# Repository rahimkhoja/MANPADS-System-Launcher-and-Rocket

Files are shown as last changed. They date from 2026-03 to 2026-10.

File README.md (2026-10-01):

# MANPADS Rocket & Launcher Prototype

> **Fork notice:** This is an enhanced fork of the original project. The simulation framework,
> firmware improvements, and documentation were developed with the assistance
> of [Cursor](https://cursor.com), an AI-powered code editor, running
> analysis on the Digital Research Alliance of Canada's Eureka HPC cluster.

---

## 30 Second Overview

30 Second Overview (https://www.youtube.com/shorts/zFn__6_LdTc)

## Full System Overview (5 Minutes)

Full System Overview (https://www.youtube.com/watch?v=DDO2EvXyncE&t=59s)

---

## Project Overview

A proof-of-concept prototype of a low-cost rocket launcher and guided rocket
system built using consumer electronics and 3D-printed components.

The rocket uses folding fins and canard stabilisation controlled by an onboard
ESP32 flight computer and MPU6050 IMU. The launcher integrates GPS, compass,
and barometric sensors to provide telemetry.

Total hardware cost: approximately **$96**.

---

## What's New in This Fork

### 6-DOF Flight Simulation
A complete rigid-body simulation modelling aerodynamic forces, motor thrust,
wind disturbance (Dryden turbulence), and quaternion-based attitude dynamics.
Used to optimise PID gains and validate flight reliability.

### PID Gain Optimisation
Differential evolution over roll PID (and optional **six-axis** roll+pitch
objective via `pid_optimizer.py --six-axis`). Expanded gain bounds (Kd up to 5).
Cluster: `run_pid_optimizer.sh` (roll-only default), `run_pid_sixaxis.sh` for
pitch-augmented tuning.

### Monte Carlo Reliability Analysis
Statistical assessment of flight performance under parameter uncertainty
(mass, thrust, wind, launch angle, sensor noise). Reports success rates
and confidence intervals.

### Extended Kalman Filter (V5 Firmware)
Drift-free attitude estimation fusing gyroscope and accelerometer data.
Automatic apogee detection. Backward-compatible with the V4 launcher.

### Aerodynamic Design Improvement
Barrowman method sweep of 38,880 configurations to find optimal fin, canard,
and nose cone geometry. Von Karman nose, larger folding fins, and boat tail
improved stability from -4.3 to +1.1 calibres and increased roll authority by
40x. Candidate STLs generated parametrically for CFD validation.

### OpenFOAM CFD Integration
Automated steady-state RANS (k-omega SST) pipeline with snappyHexMesh,
parametric Python driver, and SLURM job scripts. **`run_cfd.sh` uses
`--serial-mesh`** (serial snappyHexMesh, parallel `simpleFoam`) and sources
Lmod under bash for reliable OpenFOAM modules on Eureka.

### Rail Launcher Redesign
The improved rocket's canards exceed the original 95 mm tube bore. A parametric
rail launcher (two parallel 2020 aluminium extrusion rails + base plate) replaces
the tube design, with nylon rail buttons on the rocket body.

### Material Recommendations
See [MATERIALS.md](docs/MATERIALS.md) for recommended materials per component.

### HPC Integration
SLURM job scripts for the Eureka cluster with proper module loading,
parallel execution, and automated pipelines.

---

## Repository Structure

```
├── Firmware/
│   ├── Rocket/src/            # ESP32 flight computer (V4 + V5)
│   ├── Launcher/src/          # ESP32 ground station
│   └── dashboard.py           # Python GUI
├── Simulation/
│   ├── src/                   # 6-DOF sim, optimiser, Monte Carlo, Barrowman
│   ├── cfd/                   # OpenFOAM templates and CFD driver
│   ├── jobs/                  # SLURM job scripts
│   └── results/               # Output data and candidate STLs
├── cad/                       # STL exports (Unix-friendly names)
│   └── fusion360/             # Original Fusion 360 .f3z archives
├── Mechanical/                # Legacy CAD location
├── OpenRocket/                # Aerodynamic stability analysis
└── docs/
    ├── AERODYNAMICS.md        # Barrowman analysis, design sweep, CFD
    ├── WIRING.md              # Pin assignments (verified against firmware)
    ├── SIMULATION.md          # Simulation framework guide
    ├── FIRMWARE_IMPROVEMENTS.md  # V4 → V5 changelog
    ├── CLUSTER_GUIDE.md       # Eureka HPC usage guide
    └── CONTRIBUTING.md        # Fork details, credits, workflow
```

---

## Quick Start

### Run the Simulation Locally
```bash
cd Simulation
python3 -m venv .venv && source .venv/bin/activate
pip install numpy scipy trimesh matplotlib
python src/rocket_dynamics.py
```
Motor **total impulse is enforced at 10 N·s** (thrust curve is scaled); expect
lower apogee than an unscaled 15 N plateau used in older runs.

### Run on Eureka Cluster
```bash
cd Simulation/jobs
sbatch run_validation.sh       # Quick smoke test (< 2 min)
sbatch run_full_analysis.sh    # Full pipeline (optimise → Monte Carlo)
```

### Build the Firmware
```bash
cd Firmware/Rocket
pio run                        # Compile
pio run -t upload              # Flash to ESP32
```

---

## Documentation

| Document | Description |
|---|---|
| [AERODYNAMICS.md](docs/AERODYNAMICS.md) | Barrowman analysis, design sweep, CFD pipeline |
| [SIMULATION.md](docs/SIMULATION.md) | Simulation physics, running instructions, parameters |
| [FIRMWARE_IMPROVEMENTS.md](docs/FIRMWARE_IMPROVEMENTS.md) | V4 → V5 firmware changes |
| [CLUSTER_GUIDE.md](docs/CLUSTER_GUIDE.md) | Eureka SLURM cluster usage |
| [CONTRIBUTING.md](docs/CONTRIBUTING.md) | Fork details, credits, AI workflow |
| [MATERIALS.md](docs/MATERIALS.md) | Recommended materials per component |
| [WIRING.md](docs/WIRING.md) | Pin assignments and telemetry protocol |

---

## Full Development Media
https://drive.google.com/drive/folders/17zpks6_R59H0iXJaGkTrtp1SzIFFAQtY?usp=drive_link

---

## Credits

- **Original project:** [rahimkhoja/MANPADS-System-Launcher-and-Rocket](https://github.com/rahimkhoja/MANPADS-System-Launcher-and-Rocket)
- **Fork maintainer:** Rahim Khoja ([@rahimkhoja](https://github.com/rahimkhoja))
- **AI-assisted development:** [Cursor](https://cursor.com)
- **HPC resources:** Digital Research Alliance of Canada — Eureka cluster

*Last updated: March 2026*

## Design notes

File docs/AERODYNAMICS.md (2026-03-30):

# Aerodynamic Analysis and Design Improvement

## Overview

This document describes the aerodynamic analysis pipeline used to improve the
rocket's all-weather performance. Starting from the original CAD geometry
(measured from STL exports), we applied the Barrowman method to sweep 38,880
design configurations, identified optimal fin/canard/nose parameters, and
validated the improvement through 6-DOF simulation with Monte Carlo analysis.

## Problem Statement

The original rocket achieved only **10.4% Monte Carlo success rate** under
0–5 m/s wind conditions. Root cause analysis revealed inadequate roll control
authority: the canards barely protruded beyond the 75 mm body tube, producing
insufficient torque to counter crosswind disturbances during the 1.2 s motor
burn.

## Baseline Geometry (from CAD STL)

Dimensions extracted from `cad/rocket_assembly.stl` using trimesh:

| Parameter | Value |
|---|---|
| Total length | 587 mm |
| Body OD | 75 mm |
| Nose length | 38 mm (ogive) |
| Nose shape | Short ogive |
| Canard protrusion | ~2.6 mm beyond body |
| Fin protrusion | ~2.6 mm beyond body |
| Launcher type | Rail launcher (replaced 95 mm tube) |

**Barrowman analysis of baseline:**
- CN_alpha total: 2.05 /rad
- CP: 124 mm from nose
- Stability: **-4.33 calibres** (unstable without large fins deployed)
- Cd0: 0.70
- Roll authority: 0.000007 Nm/(rad·Pa)

## Analysis Methods

### Barrowman Method (`Simulation/src/barrowman.py`)

Implementation of the Barrowman (1966) subsonic aerodynamic prediction method:

- **Normal force slopes** for nose, fins, and canards using the corrected
  Barrowman equation:
  ```
  CNa = K_fb × 4N(s/d)² / (1 + sqrt(1 + (AR/(2·cos(Λ)))²))
  ```
  where K_fb is the fin-body interference factor, N is fin count, s is
  semi-span, d is body diameter, AR is aspect ratio, and Λ is sweep angle.

- **Center of pressure** via weighted average of component CPs.

- **Drag estimation** using turbulent flat-plate skin friction (Schlichting),
  base drag, nose pressure drag, and fin leading-edge bluntness drag.

- **Roll authority** computed as canard count × planform area × 3D lift slope
  × moment arm.

Supports conical, ogive, Von Karman, and parabolic nose cones; trapezoidal
fins and canards with arbitrary sweep.

### Parametric Geometry Generator (`Simulation/src/rocket_geometry.py`)

Generates watertight STL meshes from parametric inputs using trimesh:
- Nose cone (conical, ogive, Von Karman)
- Cylindrical body tube with optional boat tail
- Trapezoidal fin sets at arbitrary positions
- Flat-plate canard sets

### OpenFOAM CFD (`Simulation/cfd/`)

Steady-state RANS simulation using k-omega SST turbulence model:
- `snappyHexMesh` for mesh generation around STL geometry
- `simpleFoam` for incompressible steady-state solution
- Parametric Python driver (`run_case.py`) sets velocity, AoA, and STL
- Extracts Cd, Cl, Cm from converged force coefficients

## Design Sweep Results

The design sweep (`Simulation/src/design_sweep.py`) evaluated **38,880
configurations** varying:

| Parameter | Range |
|---|---|
| Nose shape | conical, ogive, Von Karman |
| Nose length | 60 – 120 mm |
| Canard span | 10 – 30 mm |
| Canard root chord | 25 – 45 mm |
| Canard position | 60 – 100 mm from nose |
| Fin span | 30 – 60 mm |
| Fin root chord | 50 – 90 mm |
| Fin sweep | 30° – 60° |
| Boat tail | yes / no |

### Scoring Criteria

1. **Must fit** within 240 mm deployed OD (rail launcher, no tube bore constraint)
2. **Stability** ≥ 1.0 calibres (CP aft of CG)
3. **Maximise** roll authority (canard torque per radian)
4. **Minimise** drag (Cd0)

### Winning Configuration

| Parameter | Baseline | Improved | Change |
|---|---|---|---|
| Nose shape | ogive (38mm) | Von Karman (120mm) | 3.2× longer |
| Fin span | 2.6 mm | 60 mm | 23× larger |
| Fin root chord | ~20 mm | 70 mm | 3.5× larger |
| Fin sweep | ~45° | 30° | Lower sweep |
| Canard span | 2.6 mm | 20 mm | 7.7× larger |
| Canard root chord | ~20 mm | 45 mm | 2.3× larger |
| Boat tail | No | Yes (30mm, 60mm end ∅) | Added |
| **Stability** | **-4.33 cal** | **1.06 cal** | **Stable** |
| **CNa** | **2.05** | **8.21 /rad** | **4.0×** |
| **Cd0** | **0.70** | **0.64** | **-9%** |
| **Roll authority** | **7e-6** | **3e-4** | **40.8×** |

## Key Design Insights

1. **The body dominates**: A 75 mm diameter, 587 mm long body creates
   substantial destabilising lift (CN_alpha = 2.0 from nose alone). Without
   proportionally large fins, the rocket is deeply unstable.

2. **Folding fins must be aggressive**: The original 2.6 mm fin protrusion
   contributes almost nothing. To overcome the body destabilisation, fins need
   60 mm semi-span (total deployed OD ~195 mm).

3. **Longer nose reduces drag**: Extending from 38 mm ogive to 120 mm Von
   Karman reduces nose pressure drag substantially while barely affecting CP.

4. **Canard sizing for roll authority**: The 40× improvement in roll authority
   comes primarily from the 7.7× increase in canard span (torque scales with
   span × chord × lift slope).

5. **Boat tail reduces base drag**: A 30 mm boat tail taper reduces the base
   drag coefficient by approximately 25%.

## Simulation Validation

The improved design parameters are integrated into `Simulation/src/rocket_dynamics.py`
as the default `RocketParameters`. PID gains were re-optimised using differential
evolution on the Eureka cluster, followed by a 2000-run Monte Carlo analysis.

See `Simulation/results/` for the latest optimisation and Monte Carlo output
files.

## Reproducing the Results

```bash
# Run the design sweep (or re-use JSON + export STLs only)
cd Simulation/src
python design_sweep.py --output ../results/sweep_results.json --generate-stl ../results/candidate_stls/ --top 5
python design_sweep.py --from-json ../results/sweep_results.json --generate-stl ../results/candidate_stls --top 5

# Run the Barrowman calculator standalone
python barrowman.py

# Generate a parametric rocket STL
python rocket_geometry.py --nose vonkarman --nose-length 0.120 --fin-span 0.060 --canard-span 0.020 --boat-tail --output improved_rocket.stl

# Run CFD (requires OpenFOAM; --serial-mesh recommended on clusters)
cd ../cfd
python run_case.py --stl ../../cad/rocket_assembly.stl --velocity 40 --aoa 0 \
  --output baseline_cfd --serial-mesh

# Submit cluster jobs
cd ../jobs
sbatch run_design_sweep.sh
sbatch run_pid_optimizer.sh
sbatch --dependency=afterok:<pid_job_id> run_monte_carlo.sh
sbatch run_cfd.sh ../../cad/rocket_assembly.stl
```

## CFD Validation Status

CFD validation using OpenFOAM is in progress. Previous runs failed due to patch
naming mismatches and oversized background meshes. These issues have been fixed
(see `Simulation/cfd/template/` changes) and new runs are being submitted. Once
complete, CFD-derived Cd/Cl/Cm will be compared to Barrowman predictions.

## References

- J.S. Barrowman, "The Theoretical Prediction of the Center of Pressure",
  SRAD, 1966.
- OpenFOAM v2412, k-omega SST turbulence model.
- Schlichting, H., "Boundary Layer Theory", 7th ed., for skin friction
  correlations.

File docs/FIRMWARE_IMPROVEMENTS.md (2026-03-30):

# Firmware Improvements: V4 → V5

This document describes the changes made to the rocket flight computer firmware.

---

## Summary of Changes

| Feature | V4 (Original) | V5 (Improved) |
|---|---|---|
| Attitude estimation | Raw gyro integration | Extended Kalman Filter (EKF) |
| Drift compensation | None | Online gyro bias estimation |
| Control axes | Roll only | Roll only (PID, same structure)  |
| D-term source | Gyro rate | Gyro rate (minus estimated bias) |
| Integral term | None | Optional Ki with anti-windup |
| Default gains | Kp=0.5, Kd=0.2 | Kp=4.51, Ki=0.32, Kd=3.67 |
| Flight phase detection | Manual state machine | Automatic apogee detection |
| Telemetry format | Fixed V4 format | V4 (default) or V5 extended |
| I2C clock | Default (100 kHz) | 400 kHz Fast Mode |

---

## Extended Kalman Filter

The EKF fuses gyroscope and accelerometer data to produce drift-free attitude
estimates. It runs at the full IMU rate (~200 Hz) and estimates:

- Roll, pitch, yaw angles (quaternion internally)
- Gyroscope bias on all three axes

### Why it matters
The MPU6050 gyroscope has a typical bias instability of ~0.01°/s. With raw
integration (V4), this produces ~0.6°/minute of drift. Over a 10-second flight
this is small, but the EKF also filters high-frequency noise and provides
pitch/yaw estimates needed for future 3-axis control.

### Implementation
The EKF is implemented in `Firmware/Rocket/src/attitude_ekf.h` as a single header
(included by `main_improved.cpp`). `getGyroBiasXRaw()` exposes the X gyro bias
in **rad/s** (native EKF units). The D-term computation subtracts this from the
raw gyro reading before converting to deg/s, ensuring correct units throughout.

---

## PID Control

V5 keeps the same roll-only control architecture as V4: all four canards
deflect by the same amount. The PID output is:

```
output = Kp × roll + Ki × ∫roll + Kd × roll_rate
```

The D-term uses the gyro rate directly (with bias removed by the EKF), not
`d(error)/dt`. This avoids amplifying sensor noise through numerical
differentiation — a deliberate design choice inherited from V4.

### Gain Derivation
Default gains (Kp=4.51, Ki=0.32, Kd=3.67) were found via differential evolution
on the Eureka HPC cluster. See `docs/SIMULATION.md` and
`Simulation/results/best_gains_roll.json` for the optimised values.

### Serial commands
- **`PID,Kp,Kd`** — V4-compatible (sets Ki=0).
- **`PID,Kp,Ki,Kd`** — full three-term set (V5).

### Battery telemetry (optional)
GPIO **36** (ADC1) with a 100k:100k divider can report bus voltage in extended
telemetry (`readBatteryVoltage()`). Define `BATTERY_ADC_PIN` to `-1` to disable.

---

## Apogee Detection

V5 adds automatic transition to RECOVERY state:

1. During FLIGHT, monitor axial accelerometer reading
2. If |accel_x| < 0.5g for 500 ms continuously → declare apogee
3. Set state to RECOVERY, centre all canards
4. Send `RECOVERY` message to launcher

This replaces the V4 behaviour where the rocket stays in FLIGHT until power-off.

---

## Telemetry

### V4 Compatible Mode (default)
```
DATA,ax,ay,az,roll,rate,offset,state,Kp,Kd,skew
```
This is identical to V4 and works with the existing launcher firmware and
dashboard without modification.

### V5 Extended Mode
```
DATA,roll,pitch,yaw,offset,state,Kp,Ki,Kd,biasX,Vbatt
```
(`Vbatt` in volts; 0 if ADC disabled.)
Activated by sending `TELEMETRY_V5` command. Returns to V4 format with
`TELEMETRY_V4`.

---

## Backward Compatibility

V5 is a drop-in replacement for V4:
- Same pin assignments
- Same serial protocol
- Same default telemetry format
- Same command set (ARM, IGNITE, CALIBRATE, PID with optional Ki)
- Added commands (DISARM, TELEMETRY_V5, TELEMETRY_V4) are additive

The launcher firmware does not need to be modified.

---

## Building

The firmware is a PlatformIO project:

```bash
cd Firmware/Rocket
pio run                    # Compile
pio run --target upload    # Flash to ESP32
pio device monitor         # Serial monitor
```

Requires: Arduino framework, Adafruit MPU6050, ESP32Servo libraries.

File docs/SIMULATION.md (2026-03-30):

# Simulation Framework

A 6-DOF (six degrees of freedom) simulation of the canard-stabilised rocket, used
to optimise PID gains and validate flight reliability under uncertainty.

---

## Architecture

```
Simulation/
├── src/
│   ├── rocket_dynamics.py   # 6-DOF physics engine
│   ├── pid_optimizer.py     # DE + grid (roll-only or --six-axis)
│   ├── monte_carlo.py       # Statistical flight analysis
│   ├── design_sweep.py      # Barrowman sweep + STL export
│   ├── barrowman.py         # Barrowman aerodynamics
│   ├── rocket_geometry.py   # Parametric STL (trimesh)
│   ├── kalman_filter.py     # EKF implementation + C++ header generator
│   └── rl_controller.py     # Reinforcement learning (PPO) controller
├── jobs/
│   ├── run_validation.sh    # Quick < 2 min smoke test
│   ├── run_pid_optimizer.sh # Gain optimisation job
│   ├── run_monte_carlo.sh   # Monte Carlo analysis job
│   ├── run_rl_training.sh   # RL training job (GPU)
│   └── run_full_analysis.sh # Full pipeline
├── results/                 # Output directory for all runs
└── requirements.txt         # Python dependencies
```

---

## Physics Model (`rocket_dynamics.py`)

### Coordinate System
NED (North-East-Down). The body x-axis points along the rocket's longitudinal axis
(out the nose). Altitude is `-position[2]`.

### Forces Modelled
| Force | Description |
|---|---|
| Thrust | Trapezoidal profile **scaled** so ∫F dt = 10 N·s (C-class) |
| Gravity | Transformed to body frame via rotation matrix |
| Aerodynamic drag | Axial, based on Cd0 + incremental canard drag |
| Normal force | CNa-based restoring force from body + fins |
| Canard lift | Per-canard flat-plate lift from deflection angle |

### Moments Modelled
| Moment | Description |
|---|---|
| Roll/pitch/yaw (canard) | Differential [L,R,U,D] deflections → moments via `mix_canards` |
| Roll damping | Clp × q̄Sd × (d/2V) × p |
| Pitch restoring | CNa × stability_margin × α × q̄SL |
| Pitch damping | Cmq × q̄SL × (d/2V) × q |
| Yaw restoring | CNa × stability_margin × β × q̄SL |
| Yaw damping | Cnr × q̄SL × (d/2V) × r |

### Wind Model
Dryden-style turbulence with a first-order filter (time constant τ = 0.5 s) applied
to white noise. No per-timestep RNG reseeding — the state is continuous.

### Integration
4th-order Runge-Kutta at 200 Hz (dt = 0.005 s). Quaternion-based attitude to avoid
gimbal lock.

---

## Controller

`CanardController` runs independent PIDs on roll, pitch, and yaw (set pitch/yaw
gains to zero for roll-only, matching V4/V5 firmware). D-term uses body angular
rate in deg/s (same convention as the rocket firmware). Outputs are mixed to four
surfaces:

`[L,R,U,D] = mix(roll_cmd, pitch_cmd, yaw_cmd)` with saturation on the 4-vector.

`pitch_rms_burn` in results is RMS deviation from **launch pitch** during burn.

---

## Running Locally

```bash
cd Simulation/src

# Single simulation
python rocket_dynamics.py

# Small grid search
python pid_optimizer.py --method grid --grid-points 5 --wind-speeds 0 3 --num-runs 1

# Small Monte Carlo
python monte_carlo.py --runs 100 --seed 42

# Six-axis PID tuning (roll + pitch in objective)
python pid_optimizer.py --method de --six-axis --workers 8

# Re-export top STLs from saved sweep (no full 38k re-sweep)
python design_sweep.py --from-json ../results/sweep_results.json \
  --generate-stl ../results/candidate_stls --top 5

# Generate Kalman filter C++ header
python kalman_filter.py
```

---

## Running on SLURM Cluster

```bash
cd Simulation/jobs

# Quick validation (< 2 minutes, 4 CPUs)
sbatch run_validation.sh

# PID optimisation (DE, ~1-2 hours, 16 CPUs)
sbatch run_pid_optimizer.sh

# Monte Carlo (2000 runs, ~1 hour, 16 CPUs)
sbatch run_monte_carlo.sh

# Optional: six-axis PID (overwrites best_gains.json — merge with roll-only if needed)
sbatch run_pid_sixaxis.sh

# CFD sweep (bash + Lmod + --serial-mesh inside driver)
sbatch run_cfd.sh ../../cad/rocket_assembly.stl

# Full pipeline (optimise → MC → report)
sbatch run_full_analysis.sh
```

Monitor with `squeue -u $USER` and check output in `Simulation/results/`.

---

## PID Optimisation

### Differential Evolution
- Population: 40, Generations: 60 (defaults; jobs may use 30×40)
- Wind speeds: 0, 2, 5 m/s crosswind
- Objective: minimise roll RMS during burn; with `--six-axis`, roll RMS + 0.25× pitch RMS (burn)
- Roll-only bounds: Kp_roll ∈ [0.05, 5.0], Ki_roll ∈ [0, 0.5], Kd_roll ∈ [0.05, 5.0]
- Six-axis adds Kp/Ki/Kd_pitch with yaw slaved to 0.2× pitch gains in the optimiser

### Grid Search
For verification. Tests a grid of Kp × Ki × Kd values.

Results are saved to mode-specific files to prevent overwrites:
- `results/best_gains_roll.json` — roll-only DE/grid results
- `results/best_gains_sixaxis.json` — six-axis DE results
- `results/best_gains.json` — copy of the latest run (either mode)

**Warning:** `best_gains.json` is always overwritten by the most recent
optimiser run. Use the mode-specific files for reproducibility.

---

## Monte Carlo Analysis

- Randomises: mass, CG, inertia, drag, thrust, wind speed/direction, launch angle
- Success criteria: altitude > 20 m, roll RMS during burn < 15°; if `Kp_pitch > 0.01`, also pitch RMS (burn) < 30°
- Default: 2000 runs with parallel execution
- Reports success rate, altitude distribution, roll statistics; **`elapsed_seconds`** is recorded correctly in the JSON summary

Results are saved to `results/monte_carlo_results.json`.

---

## Key Parameters (Improved Design)

| Parameter | Value | Source |
|---|---|---|
| Mass | 200 g | BOM estimate |
| Length | 669 mm | STL measurement (120mm nose + 549mm) |
| Diameter | 75 mm | STL measurement |
| Stability margin | 1.06 cal | Barrowman analysis |
| Motor impulse | 10 N·s | C-class solid |
| Peak thrust | 15 N | Motor data |
| Burn time | 1.2 s | Motor data |
| Canard area | 9.0 cm²  | Per canard (20×45 mm planform, improved) |
| Canard span | 20 mm | Semi-span beyond body |
| Fin span | 60 mm | Semi-span, folding |
| CNa | 8.2/rad  | Barrowman |
| Cd0 | 0.64 | Barrowman (Von Karman + boat tail) |

See [AERODYNAMICS.md](AERODYNAMICS.md) for the full design sweep methodology
and the comparison between baseline and improved configurations.

---

## Barrowman Aerodynamics

The `Simulation/src/barrowman.py` module implements the Barrowman (1966) method
for rapid aerodynamic coefficient estimation. It can evaluate a complete rocket
configuration in under 1 ms, enabling grid sweeps of tens of thousands of
designs.

```bash
python Simulation/src/barrowman.py
```

## OpenFOAM CFD

For higher-fidelity validation, the `Simulation/cfd/` directory provides an
automated OpenFOAM pipeline:

```bash
# Set up and run a single case (add --serial-mesh if parallel snappyHexMesh crashes)
python Simulation/cfd/run_case.py --stl cad/rocket_assembly.stl --velocity 40 --aoa 5 --serial-mesh

# Submit a full sweep on SLURM (script enables --serial-mesh and bash+Lmod)
cd Simulation/jobs
sbatch run_cfd.sh ../../cad/rocket_assembly.stl
```

See the [AERODYNAMICS.md](AERODYNAMICS.md) documentation for details.

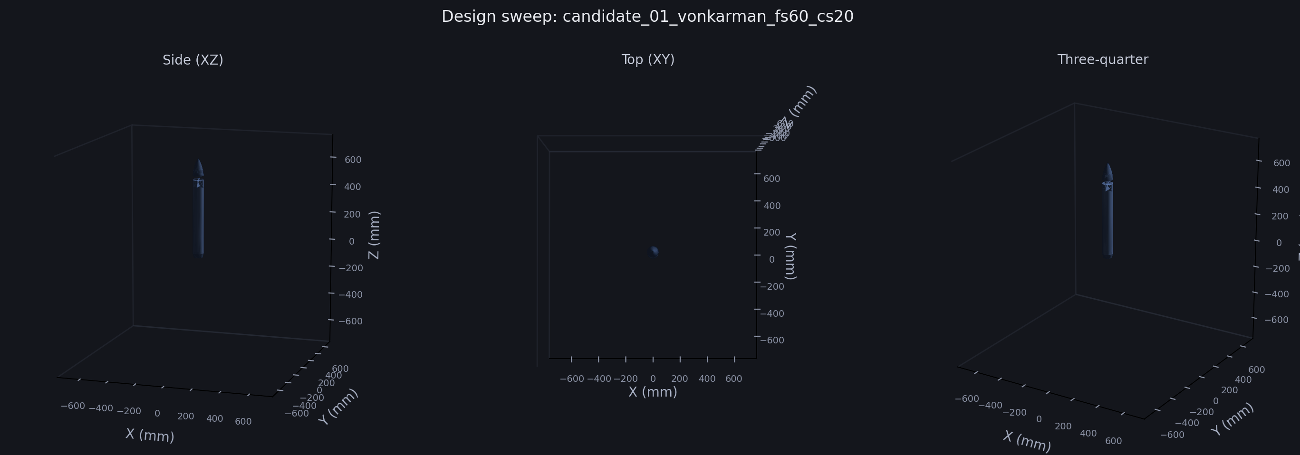
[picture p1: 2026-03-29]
docs/cad-previews/candidate_01_vonkarman_fs60_cs20.png

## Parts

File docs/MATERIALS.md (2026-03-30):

# Recommended Materials

Material recommendations per component, optimised for low cost, availability, and adequate strength at the loads this rocket sees.

## Rocket

| Component | Material | Rationale |
|---|---|---|
| **Nose cone** | 3D-printed PLA or PETG | Low stress; PLA is cheapest, PETG for outdoor heat tolerance |
| **Body tube** | Fiberglass or thin-wall carbon-fibre tube (75 mm OD) | Survives motor mount thermal load and bending at fin root better than PLA |
| **Fins (tail)** | Glass-filled nylon (SLS/MJF) or thin CFRP sheet | Needs high stiffness under aero load; folding hinge root is the critical joint |
| **Canards** | Glass-filled nylon or PETG | Must handle servo torque and aero side-load; glass nylon preferred |
| **Motor mount** | Aluminium retainer ring + phenolic tube | Standard model-rocket practice; phenolic insulates the body tube from exhaust heat |
| **Rail buttons** | Nylon or Delrin (acetal) | Low friction, self-lubricating on aluminium rail |
| **Fasteners** | M2/M3 stainless-steel machine screws + nylon lock nuts | Vibration-resistant; stainless avoids galvanic issues with aluminium |

## Launcher

| Component | Material | Rationale |
|---|---|---|
| **Rails** | 2020 aluminium V-slot extrusion (two parallel, ~1 m each) | Inexpensive, straight, standard hobby extrusion; V-slot guides the rail buttons |
| **Base plate** | 6 mm aluminium plate or 3D-printed PETG bracket | Needs rigidity to resist launch-force reaction; aluminium preferred outdoors |
| **Igniter mount** | 3D-printed PETG bracket + steel retainer clip | Heat-exposed but brief; PETG adequate if insulated from nozzle blast |
| **Electronics enclosure** | IP65 plastic junction box or 3D-printed PETG | Protects ESP32, battery, and servo driver from weather |

## Cost Estimates (Approximate)

| Item | Estimated Cost |
|---|---|
| Fiberglass body tube (75 mm OD × 600 mm) | $8–15 |
| Glass-filled nylon fins (SLS print, set of 4) | $15–25 |
| PETG canards (FDM, set of 4) | $2–5 |
| PLA nose cone | $1–3 |
| Aluminium motor retainer | $5–8 |
| 2020 extrusion rails (2 × 1 m) | $8–12 |
| Aluminium base plate (200 × 150 × 6 mm) | $5–10 |
| Nylon rail buttons (pair) | $1–2 |
| **Total materials (rocket + launcher)** | **~$45–80** |

Electronics, motor, and servo costs are separate and documented in the main README.

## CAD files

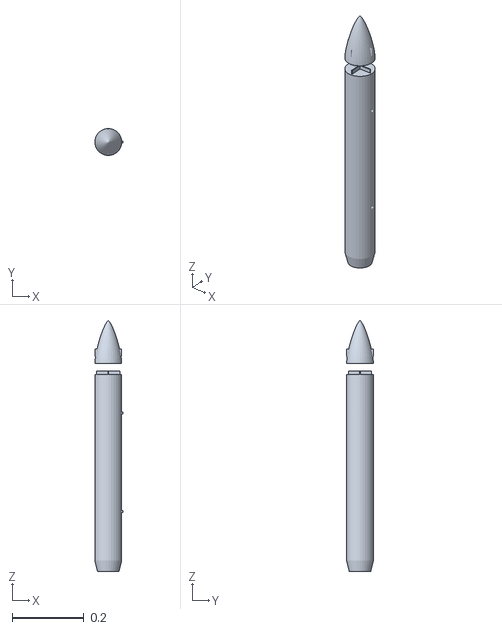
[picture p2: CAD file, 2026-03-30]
cad/rocket_assembly_rail.stl
0.079 x 0.075 x 0.699

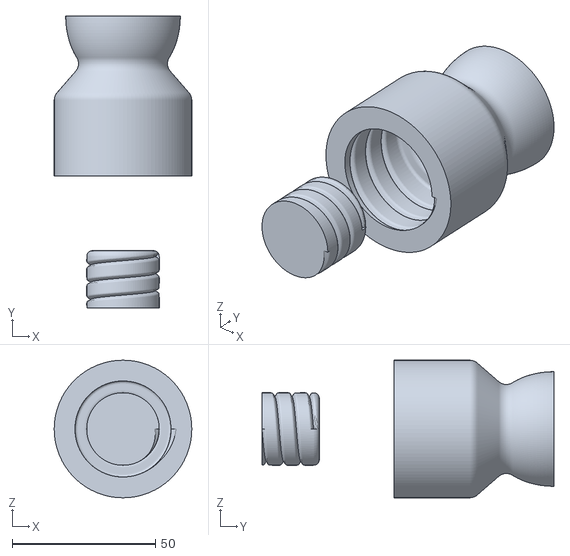
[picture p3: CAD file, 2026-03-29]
cad/nozzle_assembly.stl
48.0 x 101.9 x 48.0

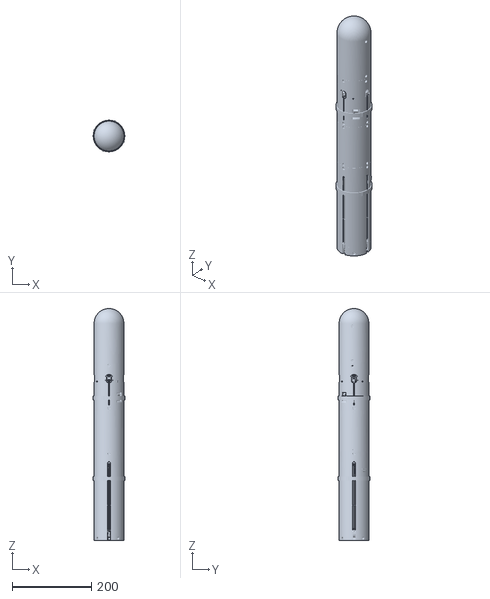
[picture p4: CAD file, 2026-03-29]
cad/rocket_assembly.stl
79.9 x 79.9 x 587.2

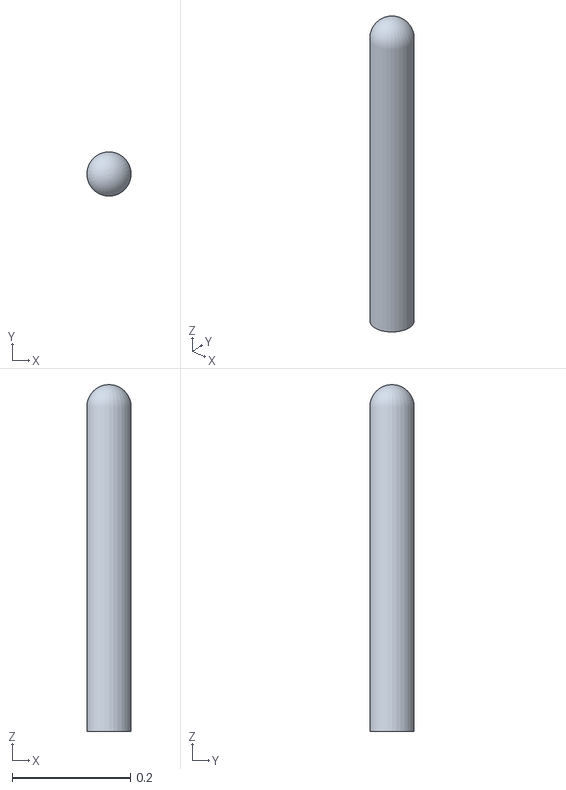
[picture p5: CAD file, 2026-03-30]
cad/rocket_baseline_clean.stl
0.075 x 0.075 x 0.587

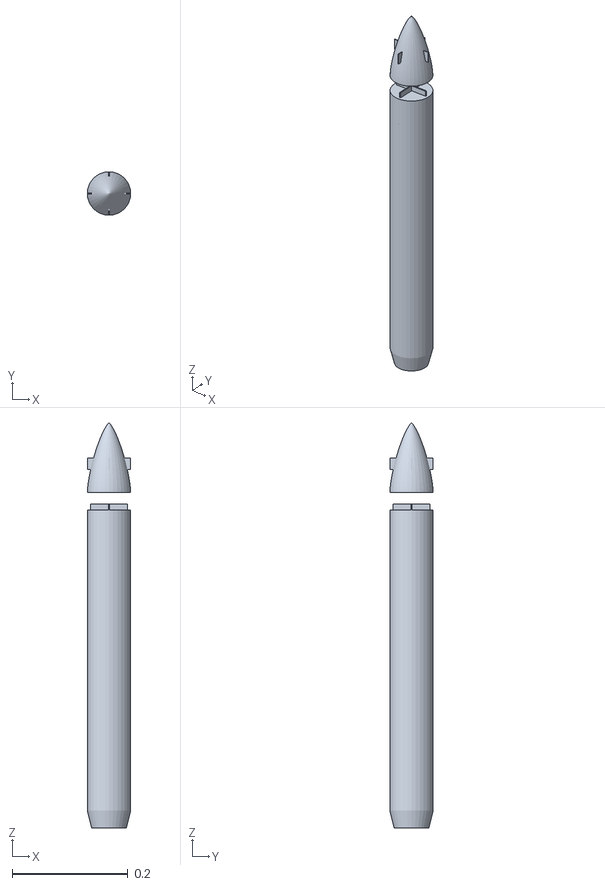
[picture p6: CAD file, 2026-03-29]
Simulation/results/candidate_stls/candidate_04_vonkarman_fs60_cs20.stl
0.075 x 0.075 x 0.699

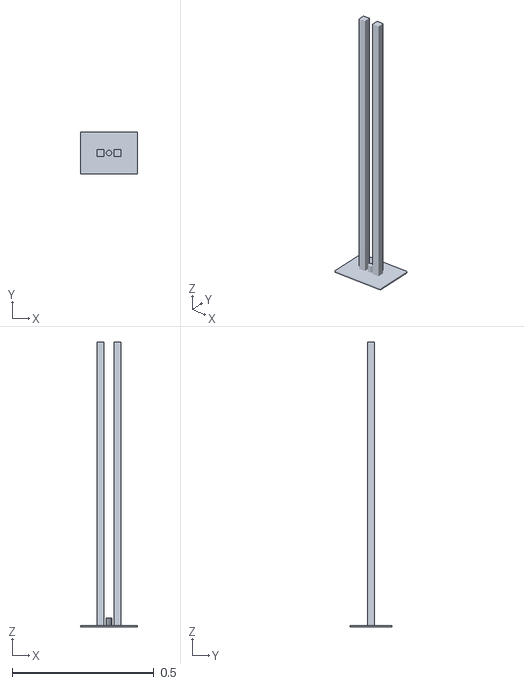
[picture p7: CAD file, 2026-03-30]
cad/rail_launcher.stl
0.2 x 0.15 x 1.01

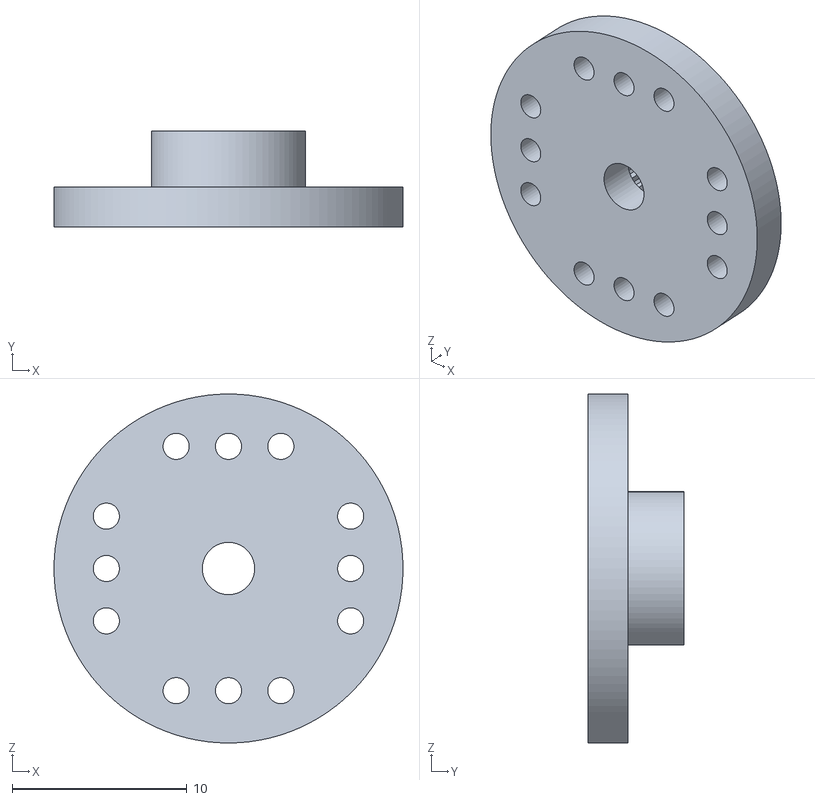
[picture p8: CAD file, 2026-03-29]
cad/servo_horns.stl
20.0 x 5.50 x 20.0

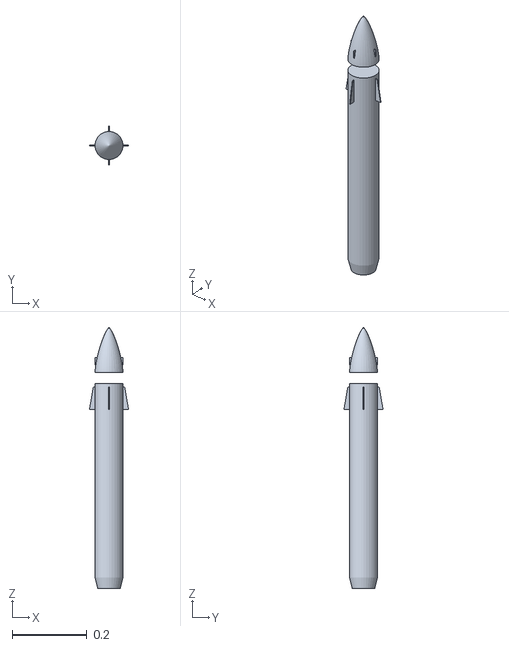
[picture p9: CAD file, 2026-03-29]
Simulation/results/candidate_stls/candidate_03_vonkarman_fs60_cs20.stl
0.105 x 0.105 x 0.699

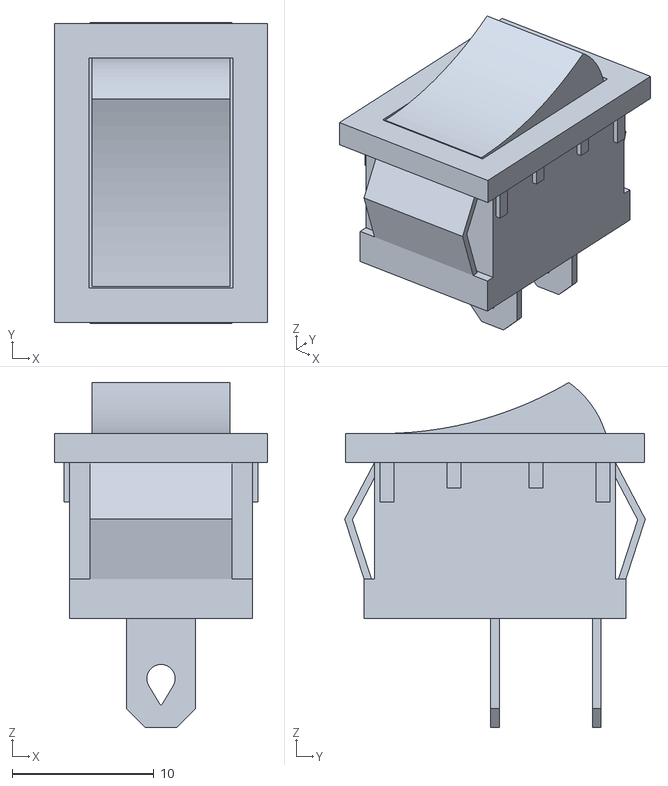
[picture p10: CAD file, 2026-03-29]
cad/power_switch.stl
15.0 x 21.2 x 24.3

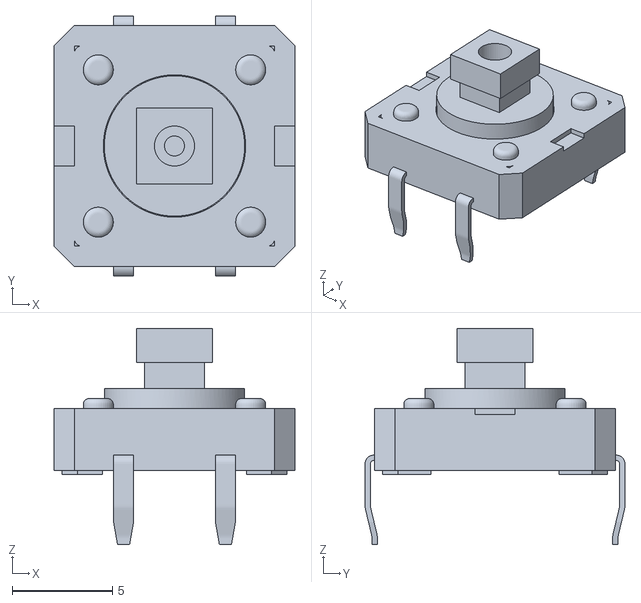
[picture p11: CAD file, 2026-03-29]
cad/microswitch.stl
12.0 x 13.0 x 10.8

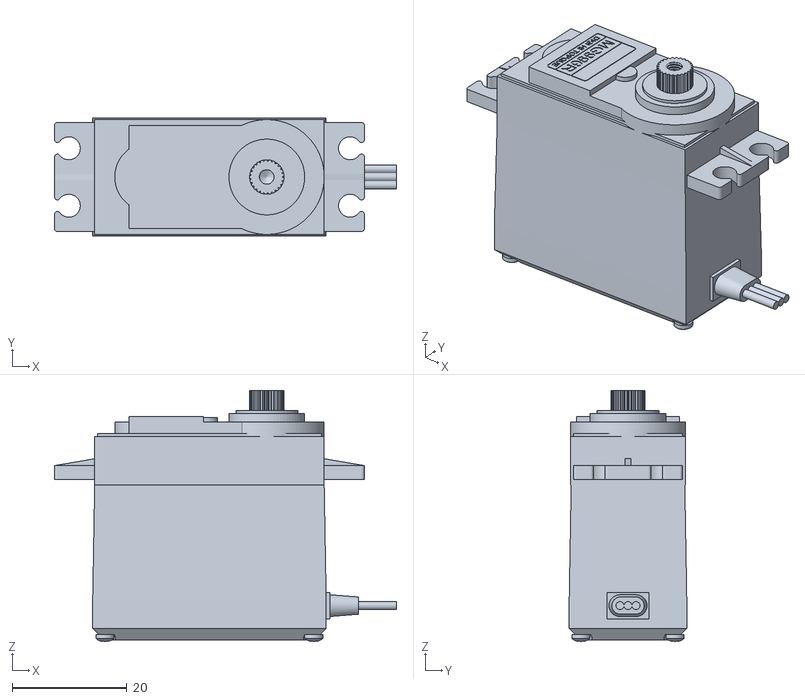
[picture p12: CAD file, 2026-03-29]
cad/servo_mg996r.stl
59.6 x 20.5 x 43.8

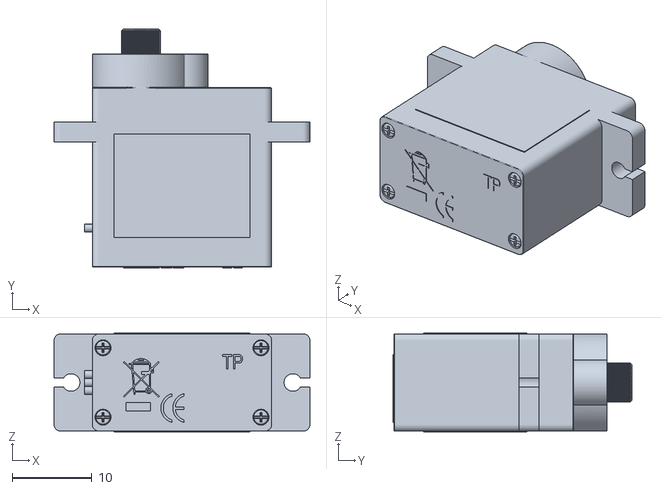
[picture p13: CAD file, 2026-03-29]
cad/servo_sg90_body_2.stl
32.1 x 29.9 x 12.4

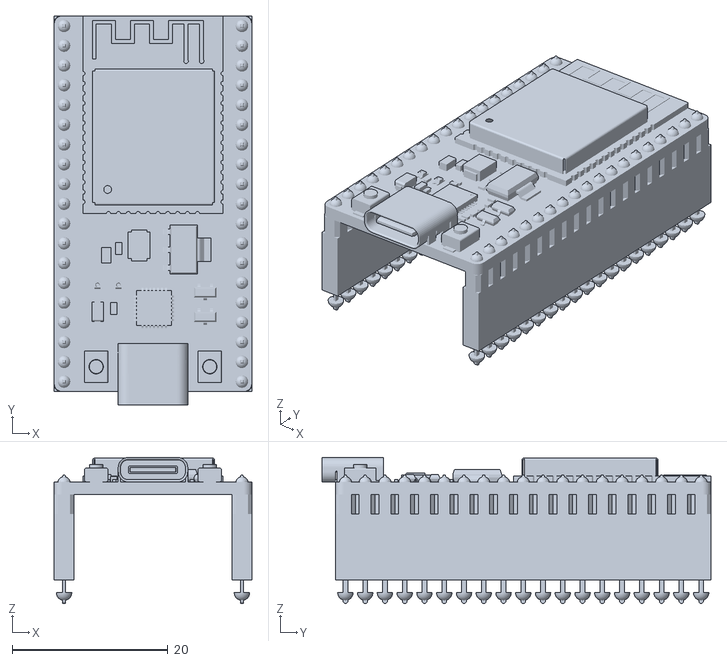
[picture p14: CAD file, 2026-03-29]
cad/esp32_wroom.stl
25.4 x 50.0 x 18.8

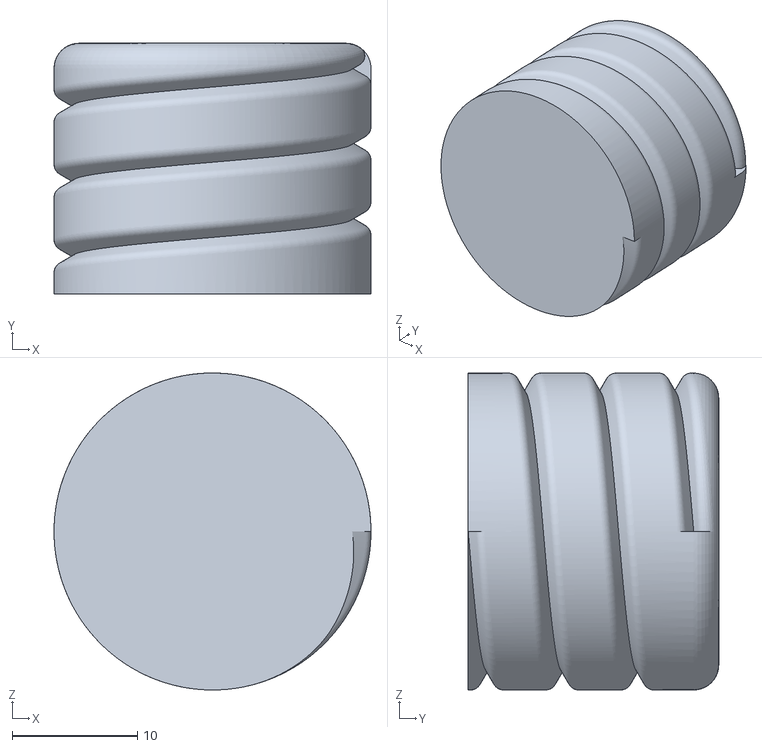
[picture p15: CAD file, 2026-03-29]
cad/nozzle_insert.stl
25.3 x 20.0 x 25.3

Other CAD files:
Simulation/results/candidate_stls/candidate_01_vonkarman_fs60_cs20.stl
Simulation/results/candidate_stls/candidate_02_conical_fs60_cs25.stl
Simulation/results/candidate_stls/candidate_05_ogive_fs60_cs20.stl
cad/fusion360/Folding Rocket.f3z
cad/fusion360/Launcher Platform.f3z
cad/fusion360/Rocket Nozzle.f3z
cad/imu_mpu6050.stl
cad/launcher_tube.stl
cad/nozzle_body.stl
cad/servo_sg90_arm.stl
cad/servo_sg90_arm_2.stl
cad/tactile_switch.stl

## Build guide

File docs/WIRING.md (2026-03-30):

# Wiring Reference

Pin assignments verified against the firmware source code (V4/V5).

---

## Rocket Flight Computer (ESP32 DevKit V1)

### Servo Connections
| Function | GPIO Pin | Notes |
|---|---|---|
| Left Canard | 26 | Left side |
| Right Canard | 25 | Right side |
| Up Canard | 27 | Top |
| Down Canard | 14 | Bottom |
| Ignition Servo | 5 | Motor bay |

### Servo Center Calibration
| Servo | Center Angle | Max Deflection |
|---|---|---|
| Left  | 115° | ±12° |
| Right | 80° | ±12° |
| Up | 80° | ±12° |
| Down  | 115° | ±12° |

### I2C Bus (MPU6050)
| Signal | GPIO Pin |
|---|---|
| SDA | 21 |
| SCL | 22 |

### UART to Launcher (Serial2)
| Signal | GPIO Pin | Baud Rate |
|---|---|---|
| TX2 | 17 | 115200 |
| RX2 | 16 | 115200 |

---

## Launcher Ground Station (ESP32 DevKit V1)

### I2C Bus (QMC5883L + BMP180)
| Signal | GPIO Pin |
|---|---|
| SDA | 21 |
| SCL | 22 |

### I2C Device Addresses
| Device | Address | Notes |
|---|---|---|
| QMC5883L  | 0x0D | Compass |
| BMP180 | 0x77 | Barometer / altimeter |

### GPS Module (Serial1)
| Signal | GPIO Pin | Baud Rate |
|---|---|---|
| RX1 | 4 | 9600 |

> GPS TX connects to ESP32 RX1 (GPIO 4). Pin 4 supports input on ESP32.

### UART to Rocket (Serial2)
| Signal | GPIO Pin | Baud Rate |
|---|---|---|
| TX2 | 17 | 115200 |
| RX2 | 16 | 115200 |

### Control Switches & Indicators
| Function | GPIO Pin | Type | Notes |
|---|---|---|---|
| Arm Switch | 5 | Toggle Switch | INPUT_PULLUP, active LOW |
| Launch Button | 18 | Momentary (N.O.)  | INPUT_PULLUP, active LOW |
| Status LED | 23 | LED | Digital output |
| Buzzer | 2 | Active Buzzer | LOW-trigger |
| Launcher Servo  | 19 | SG90 Micro Servo  | Launcher-side ignition |

### WiFi Configuration
| Parameter  | Value |
|---|---|
| Mode | SoftAP (Access Point)|
| SSID | `ROCKET_LAUNCHER` |
| Password | `launch_secure` (matches `Firmware/Launcher/src/main.cpp`) |
| IP Address | 192.168.4.1 |
| UDP Port | 4444 |

---

## Telemetry Protocol

### V4 Format (default)
| Direction | Format |
|---|---|
| Rocket → Launcher | `DATA,ax,ay,az,roll,rate,offset,state,Kp,Kd,skew` |
| Launcher → PC | `ENV,lat,lon,alt,gps_state` |
| PC → Rocket | `PID,Kp,Kd` |

### V5 Extended Format (opt-in via `TELEMETRY_V5` command)
| Direction | Format |
|---|---|
| Rocket → Launcher | `DATA,roll,pitch,yaw,offset,state,Kp,Ki,Kd,biasX,Vbatt` |

### Commands
| Command | Description |
|---|---|
| `ARM` | Arm the system (IDLE → ARMED) |
| `DISARM` | Disarm (any → IDLE) — V5 only |
| `IGNITE` | Fire ignition servo (ARMED → IGNITING) |
| `CALIBRATE` | Re-calibrate IMU |
| `PID,Kp,Kd` | Set PID gains (V4, Ki=0) |
| `PID,Kp,Ki,Kd` | Set PID gains with integral term (V5)  |
| `TELEMETRY_V5`  | Switch to extended format — V5 only |
| `TELEMETRY_V4`  | Switch back to V4 format — V5 only |

---

## Changelog

- **2026-03**: Corrected pin assignments to match firmware source (Ignition Servo: 13→5,
  Arm Switch: 15→5, Launch Button: 4→18, LED: 2→23, Buzzer: 5→2, Launcher Servo: 13→19,
  GPS RX: 34→4). Fixed max deflection: ±15°→±12°. Added V5 telemetry format.

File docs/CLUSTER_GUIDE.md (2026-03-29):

# Eureka Cluster Guide

Instructions for running the rocket simulation framework on the Digital Research
Alliance of Canada (formerly Compute Canada) Eureka cluster.

---

## Environment

| Component | Details |
|---|---|
| Scheduler | SLURM |
| Software | CVMFS module system |
| StdEnv | StdEnv/2023 |
| Python | 3.11.5 (module) |
| NumPy/SciPy  | scipy-stack/2024a (module) |
| GPUs | Available via `--gres=gpu:1` |
| CUDA | 12.2 (module) |

---

## Quick Start

```bash
# Load the software stack
module load StdEnv/2023 python/3.11.5 scipy-stack/2024a

# Create a virtual environment (one-time)
python -m venv --system-site-packages ~/rocket_venv
source ~/rocket_venv/bin/activate

# Navigate to the simulation
cd MANPADS-System-Launcher-and-Rocket/Simulation/jobs

# Run the quick validation (< 2 minutes)
sbatch run_validation.sh
```

---

## SLURM Job Scripts

| Script | CPUs | Time | Description |
|---|---|---|---|
| `run_validation.sh` | 4 | 10 min | Smoke test — verify everything works |
| `run_pid_optimizer.sh`  | 16 | 2 hr | Grid + DE roll-only gain tuning |
| `run_pid_sixaxis.sh` | 16 | 2 hr | DE with roll+pitch objective (`--six-axis`) |
| `run_monte_carlo.sh` | 16 | 2 hr | 2000-run statistical analysis |
| `run_cfd.sh` | 16 | 6 hr | OpenFOAM matrix (`--serial-mesh` in driver) |
| `run_design_sweep.sh` | 1 | 30 min | Barrowman sweep (+ optional STLs) |
| `run_rl_training.sh` | 8+GPU| 4 hr | PPO reinforcement learning |
| `run_full_analysis.sh`  | 16 | 6 hr | Complete pipeline |

### Submitting Jobs
```bash
cd Simulation/jobs
sbatch run_validation.sh          # Submit
squeue -u $USER                   # Check status
scancel <job_id>                  # Cancel
```

### Viewing Output
```bash
# Real-time output
tail -f ../results/validate_<job_id>.out

# Error log
cat ../results/validate_<job_id>.err
```

---

## Module Commands

```bash
module avail python              # List available Python versions
module avail scipy               # List scipy-stack versions
module load StdEnv/2023          # Base environment
module load python/3.11.5        # Python interpreter
module load scipy-stack/2024a    # NumPy, SciPy, matplotlib, etc.
module load cuda/12.2            # CUDA toolkit (for GPU jobs)
module list                      # Show loaded modules
module purge                     # Unload all
```

---

## Virtual Environment

SLURM jobs create a temporary venv in `$SLURM_TMPDIR` (fast local SSD) for each
job. For interactive work, create a persistent venv:

```bash
module load StdEnv/2023 python/3.11.5 scipy-stack/2024a
python -m venv --system-site-packages ~/rocket_venv
source ~/rocket_venv/bin/activate
pip install torch  # If needed for RL training
```

The `--system-site-packages` flag gives the venv access to the cluster's
pre-built NumPy/SciPy/matplotlib, which are compiled with optimised BLAS.

---

## Interactive Testing

For quick debugging without submitting a job:

```bash
module load StdEnv/2023 python/3.11.5 scipy-stack/2024a
cd MANPADS-System-Launcher-and-Rocket/Simulation/src

# Run a single simulation
python rocket_dynamics.py

# Small optimizer test
python pid_optimizer.py --method grid --grid-points 3 --num-runs 1 --wind-speeds 0 2
```

Note: the login node is shared. Keep interactive runs short (< 5 minutes) or
use `salloc` to get an interactive compute node.

---

## Parallel Execution

The optimizer and Monte Carlo scripts support parallel execution via Python's
`ProcessPoolExecutor`. The `--workers` flag controls the number of parallel
processes:

```bash
# Use all allocated CPUs
python pid_optimizer.py --workers ${SLURM_CPUS_PER_TASK}
```

Each worker runs an independent simulation, so scaling is nearly linear up to
the number of physical cores.

---

## Results

All output goes to `Simulation/results/`:

| File | Contents |
|---|---|
| `best_gains.json` | Optimised Kp, Ki, Kd gains |
| `opt_history_de.json` | Full DE convergence history |
| `monte_carlo_results.json` | MC statistics + per-run data |
| `*.out` / `*.err` | SLURM job stdout/stderr |

---

## Troubleshooting

| Problem | Solution |
|---|---|
| `ModuleNotFoundError: scipy` | `module load scipy-stack/2024a` |
| No output from job | Add `export PYTHONUNBUFFERED=1` |
| Job killed (OOM) | Increase `--mem` |
| `pickle` error in parallel | Ensure worker functions are at module level |
| Stale results | Check `--output-dir` path |

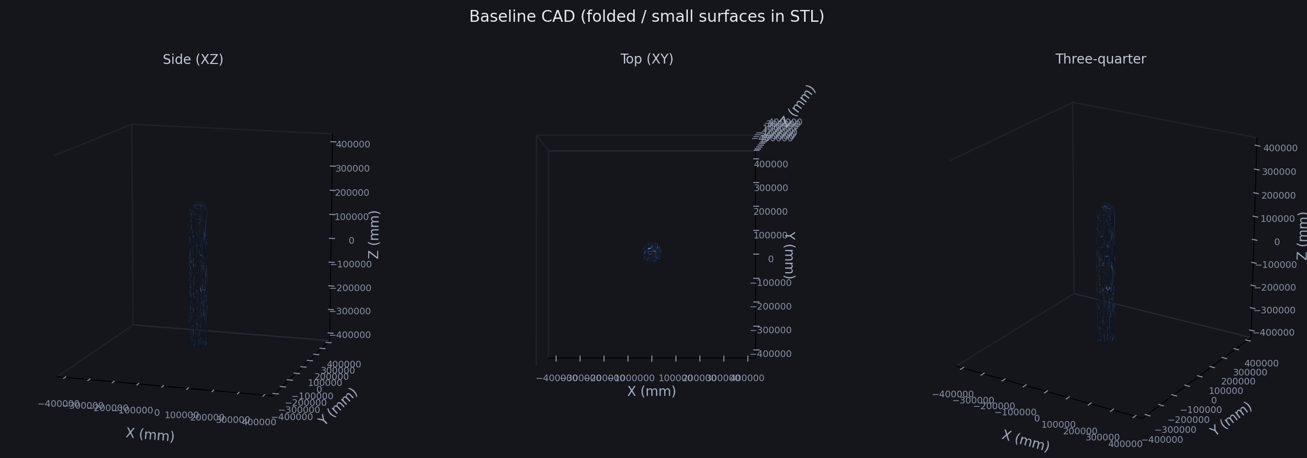
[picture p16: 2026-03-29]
docs/cad-previews/baseline_rocket_assembly.png

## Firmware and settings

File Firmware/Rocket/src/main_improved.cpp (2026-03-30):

/*
 * ROCKET ESP32 CODE — V5 (Improved)
 * ==================================
 * Enhancements over V4:
 *   - Extended Kalman Filter for drift-free attitude estimation
 *   - PID roll control with D-term from gyro rate (matches V4 convention)
 *   - Automatic apogee detection → RECOVERY state
 *   - Backward-compatible telemetry (same DATA format as V4)
 *
 * All 4 canards still deflect identically for roll stabilisation.
 * Gains are derived from simulation optimisation on HPC cluster.
 */

#include <Arduino.h>
#include <Wire.h>
#include <Adafruit_MPU6050.h>
#include <Adafruit_Sensor.h>
#include <ESP32Servo.h>
#include "attitude_ekf.h"

#ifdef ENABLE_RL_POLICY
#include "rl_policy.h"
#endif

// ============== PIN DEFINITIONS (matches V4) ==============
const int RX2_PIN = 16;
const int TX2_PIN = 17;
const int IGNITE_SERVO_PIN = 5;

const int LEFT_SERVO_PIN = 26;
const int RIGHT_SERVO_PIN = 25;
const int UP_SERVO_PIN = 27;
const int DOWN_SERVO_PIN = 14;

// ============== SERVO CALIBRATION ==============
const int IGNITE_SERVO_ON = 150;
const int IGNITE_SERVO_OFF = 35;

const int LEFT_CENTER = 115;
const int RIGHT_CENTER = 80;
const int UP_CENTER = 80;
const int DOWN_CENTER = 115;
const int MAX_DEFLECTION = 12;

// ============== ROLL CONTROL GAINS ==============
float Kp = 4.51f;
float Ki = 0.32f;
float Kd = 3.67f;
float integralLimit = 15.0f;

// Optional LiPo sense: GPIO36 + 100k:100k divider to ADC (set -1 to disable)
#ifndef BATTERY_ADC_PIN
#define BATTERY_ADC_PIN 36
#endif

static float readBatteryVoltage() {
#if BATTERY_ADC_PIN >= 0
    int mv = analogReadMilliVolts(BATTERY_ADC_PIN);
    return (mv / 1000.0f) * 2.0f; // 2:1 divider
#else
    return 0.0f;
#endif
}

// ============== HARDWARE ==============
Servo igniteServo;
Servo leftServo, rightServo, upServo, downServo;
Adafruit_MPU6050 mpu;
AttitudeEKF ekf;

// ============== STATE MACHINE ==============
enum SystemState { IDLE, ARMED, IGNITING, FLIGHT, RECOVERY };
SystemState sysState = IDLE;

enum ControlMode { PID_MODE, RL_MODE };
ControlMode controlMode = PID_MODE;

String cmdBuffer = "";

// Control variables
float rollIntegral = 0;
int lastServoOffset = 0;
float physical_skew_angle = 0.0f;
float rlCanards[4] = {0, 0, 0, 0};

// Timing
unsigned long lastTime;
unsigned long lastTelemetrySent = 0;
unsigned long lastReadySent = 0;
unsigned long igniteStartTime = 0;
unsigned long flightStartTime = 0;

// Apogee detection
float peakAltitudeAccel = 0.0f;
unsigned long lowGStartTime = 0;
const unsigned long APOGEE_HOLD_MS = 500;
const float LOW_G_THRESHOLD = 4.9f; // m/s^2 (~0.5 g)

// Telemetry mode: false = V4 compatible, true = extended V5
bool extendedTelemetry = false;

// ============== FORWARD DECLARATIONS ==============
void calibrateSensors();
void resetController();
void setAllCanards(int offset);
void setCanardsIndividual(float left, float right, float up, float down);

// ============== SETUP ==============
void setup() {
    Serial.begin(115200);
    Serial2.begin(115200, SERIAL_8N1, RX2_PIN, TX2_PIN);
    Serial2.setTimeout(20);
    delay(1500);

    Wire.begin(21, 22);
    Wire.setClock(400000);

    if (!mpu.begin()) {
        Serial.println("MPU6050 not found!");
        while (1) delay(100);
    }

    mpu.setAccelerometerRange(MPU6050_RANGE_8_G);
    mpu.setGyroRange(MPU6050_RANGE_500_DEG);
    mpu.setFilterBandwidth(MPU6050_BAND_21_HZ);

#if BATTERY_ADC_PIN >= 0
    pinMode(BATTERY_ADC_PIN, INPUT);
#endif

    ESP32PWM::allocateTimer(0);
    ESP32PWM::allocateTimer(1);

    igniteServo.setPeriodHertz(50);
    igniteServo.attach(IGNITE_SERVO_PIN);
    igniteServo.write(IGNITE_SERVO_OFF);

    leftServo.setPeriodHertz(50);   leftServo.attach(LEFT_SERVO_PIN, 500, 2400);
    rightServo.setPeriodHertz(50);  rightServo.attach(RIGHT_SERVO_PIN, 500, 2400);
    upServo.setPeriodHertz(50);     upServo.attach(UP_SERVO_PIN, 500, 2400);
    downServo.setPeriodHertz(50);   downServo.attach(DOWN_SERVO_PIN, 500, 2400);

    setAllCanards(0);
    calibrateSensors();
    ekf.reset();

    lastTime = micros();
    Serial.println("Rocket V5 Ready — EKF + Roll PID");
}

// ============== MAIN LOOP ==============
void loop() {
    unsigned long now = micros();
    float dt = (now - lastTime) / 1000000.0f;
    if (dt <= 0 || dt > 0.1f) { lastTime = now; return; }
    lastTime = now;

    sensors_event_t accel, gyro, temp;
    mpu.getEvent(&accel, &gyro, &temp);

    ekf.process(
        gyro.gyro.x, gyro.gyro.y, gyro.gyro.z,
        accel.acceleration.x, accel.acceleration.y, accel.acceleration.z,
        dt
    );

    float rollDeg = ekf.getRollDeg();
    float rollRateDeg = (gyro.gyro.x - ekf.getGyroBiasXRaw()) * RAD_TO_DEG;

    switch (sysState) {
    case IDLE:
    case ARMED:
        setAllCanards(0);
        break;

    case IGNITING:
        if (millis() - igniteStartTime > 2500) {
            igniteServo.write(IGNITE_SERVO_OFF);
            sysState = FLIGHT;
            flightStartTime = millis();
            resetController();
            Serial2.println("IGNITED");
        }
        break;

    case FLIGHT: {
#ifdef ENABLE_RL_POLICY
        if (controlMode == RL_MODE) {
            float pitch = ekf.getPitchDeg();
            float yaw = ekf.getYawDeg();
            float pitchRateDeg = (gyro.gyro.y) * RAD_TO_DEG;
            float yawRateDeg = (gyro.gyro.z) * RAD_TO_DEG;
            float speed = sqrtf(accel.acceleration.x * accel.acceleration.x +
                                accel.acceleration.y * accel.acceleration.y +
                                accel.acceleration.z * accel.acceleration.z);

            float rlState[RL_STATE_DIM] = {
                rollDeg / 45.0f,
                (pitch - 85.0f) / 45.0f,
                yaw / 45.0f,
                (gyro.gyro.x) / 5.0f,
                (gyro.gyro.y) / 5.0f,
                (gyro.gyro.z) / 5.0f,
                0.0f, 0.0f, 0.0f,
                0.0f,
                (millis() - flightStartTime) / 10000.0f,
                (millis() - flightStartTime < 1200) ? 1.0f : 0.0f
            };

            rl_policy_forward(rlState, rlCanards);

            bool rl_safe = (fabsf(rollDeg) < 45.0f) && (fabsf(pitch - 85.0f) < 45.0f);
            for (int i = 0; i < 4; i++) {
                if (fabsf(rlCanards[i]) > MAX_DEFLECTION) rl_safe = false;
            }

            if (rl_safe) {
                setCanardsIndividual(rlCanards[0], rlCanards[1], rlCanards[2], rlCanards[3]);
                lastServoOffset = (int)rlCanards[0];
            } else {
                controlMode = PID_MODE;
                Serial2.println("RL_FALLBACK:PID");
            }
        }
#endif

        if (controlMode == PID_MODE) {
            rollIntegral += rollDeg * dt;
            rollIntegral = constrain(rollIntegral, -integralLimit, integralLimit);

            float output = Kp * rollDeg + Ki * rollIntegral + Kd * rollRateDeg;
            int offset = constrain((int)output, -MAX_DEFLECTION, MAX_DEFLECTION);
            setAllCanards(offset);
            lastServoOffset = offset;
        }

        float axialAccel = accel.acceleration.x;
        if (fabsf(axialAccel) < LOW_G_THRESHOLD) {
            if (lowGStartTime == 0) lowGStartTime = millis();
            if (millis() - lowGStartTime > APOGEE_HOLD_MS) {
                sysState = RECOVERY;
                setAllCanards(0);
                Serial2.println("RECOVERY");
            }
        } else {
            lowGStartTime = 0;
        }
        break;
    }

    case RECOVERY:
        setAllCanards(0);
        break;
    }

    // Telemetry at 20 Hz
    if (millis() - lastTelemetrySent >= 50) {
        if (extendedTelemetry) {
            // V5 extended: DATA,roll,pitch,yaw,offset,state,Kp,Ki,Kd,biasX,Vbatt
            float pitch = ekf.getPitchDeg();
            float yaw = ekf.getYawDeg();
            float bx = ekf.getGyroBiasXRaw() * RAD_TO_DEG;
            const char* st = (sysState == IDLE) ? "IDLE" :
                             (sysState == ARMED) ? "ARMED" :
                             (sysState == IGNITING) ? "IGNITING" :
                             (sysState == FLIGHT) ? "FLIGHT" : "RECOVERY";
            char buf[160];
            float vb = readBatteryVoltage();
            snprintf(buf, sizeof(buf),
                "DATA,%.2f,%.2f,%.2f,%d,%s,%.2f,%.2f,%.2f,%.3f,%.2f",
                rollDeg, pitch, yaw, lastServoOffset, st, Kp, Ki, Kd, bx, vb);
            Serial2.println(buf);
        } else {
            // V4 compatible: DATA,ax,ay,az,roll,rate,offset,state,Kp,Kd,skew
            char buf[160];
            snprintf(buf, sizeof(buf),
                "DATA,%.2f,%.2f,%.2f,%.2f,%.2f,%d,%s,%.2f,%.2f,%.2f",
                accel.acceleration.x, accel.acceleration.y, accel.acceleration.z,
                rollDeg, rollRateDeg, lastServoOffset,
                (sysState == IDLE) ? "IDLE" :
                (sysState == ARMED) ? "ARMED" :
                (sysState == IGNITING) ? "IGNITING" :
                (sysState == FLIGHT) ? "FLIGHT" : "RECOVERY",
                Kp, Kd, physical_skew_angle);
            Serial2.println(buf);
        }
        lastTelemetrySent = millis();
    }

    // Heartbeat at 1 Hz
    if (sysState == IDLE && millis() - lastReadySent >= 1000) {
        Serial2.println("READY");
        lastReadySent = millis();
    }

    // Command processing
    while (Serial2.available()) {
        char c = Serial2.read();
        if (c == '\n') {
            cmdBuffer.trim();

            if (cmdBuffer == "ARM" && sysState == IDLE) {
                sysState = ARMED;
                resetController();
                Serial2.println("ACK:ARMED");
            }
            else if (cmdBuffer == "DISARM") {
                sysState = IDLE;
                Serial2.println("ACK:DISARMED");
            }
            else if (cmdBuffer == "IGNITE" && sysState == ARMED) {
                sysState = IGNITING;
                igniteStartTime = millis();
                igniteServo.write(IGNITE_SERVO_ON);
                Serial2.println("ACK:IGNITING");
            }
            else if (cmdBuffer == "CALIBRATE") {
                resetController();
                Serial2.println("ACK:CALIBRATED");
            }
            else if (cmdBuffer.startsWith("PID,")) {
                // PID,Kp,Kd  (V4 compat, Ki=0)  or  PID,Kp,Ki,Kd
                int c1 = cmdBuffer.indexOf(',');
                int c2 = cmdBuffer.indexOf(',', c1 + 1);
                int c3 = cmdBuffer.indexOf(',', c2 + 1);
                if (c1 > 0 && c2 > 0) {
                    Kp = cmdBuffer.substring(c1 + 1, c2).toFloat();
                    if (c3 > 0) {
                        Ki = cmdBuffer.substring(c2 + 1, c3).toFloat();
                        Kd = cmdBuffer.substring(c3 + 1).toFloat();
                    } else {
                        Ki = 0.0f;
                        Kd = cmdBuffer.substring(c2 + 1).toFloat();
                    }
                    Serial2.println("ACK:PID_SET");
                }
            }
            else if (cmdBuffer == "TELEMETRY_V5") {
                extendedTelemetry = true;
                Serial2.println("ACK:TELEMETRY_V5");
            }
            else if (cmdBuffer == "TELEMETRY_V4") {
                extendedTelemetry = false;
                Serial2.println("ACK:TELEMETRY_V4");
            }
            else if (cmdBuffer == "MODE_RL") {
#ifdef ENABLE_RL_POLICY
                controlMode = RL_MODE;
                Serial2.println("ACK:MODE_RL");
#else
                Serial2.println("ERR:RL_NOT_COMPILED");
#endif
            }
            else if (cmdBuffer == "MODE_PID") {
                controlMode = PID_MODE;
                Serial2.println("ACK:MODE_PID");
            }
            cmdBuffer = "";
        } else if (c != '\r') {
            cmdBuffer += c;
        }
    }
}

// ============== HELPERS ==============
void setAllCanards(int offset) {
    offset = constrain(offset, -MAX_DEFLECTION, MAX_DEFLECTION);
    leftServo.write(LEFT_CENTER + offset);
    rightServo.write(RIGHT_CENTER + offset);
    upServo.write(UP_CENTER + offset);
    downServo.write(DOWN_CENTER + offset);
}

void setCanardsIndividual(float left, float right, float up, float down) {
    leftServo.write(LEFT_CENTER + constrain((int)left, -MAX_DEFLECTION, MAX_DEFLECTION));
    rightServo.write(RIGHT_CENTER + constrain((int)right, -MAX_DEFLECTION, MAX_DEFLECTION));
    upServo.write(UP_CENTER + constrain((int)up, -MAX_DEFLECTION, MAX_DEFLECTION));
    downServo.write(DOWN_CENTER + constrain((int)down, -MAX_DEFLECTION, MAX_DEFLECTION));
}

void calibrateSensors() {
    Serial.println("Calibrating... keep still");
    delay(500);

    float sumAx = 0, sumAy = 0, sumAz = 0;
    const int samples = 200;

    for (int i = 0; i < samples; i++) {
        sensors_event_t a, g, t;
        mpu.getEvent(&a, &g, &t);
        sumAx += a.acceleration.x;
        sumAy += a.acceleration.y;
        sumAz += a.acceleration.z;
        delay(5);
    }

    float ay = sumAy / samples;
    float az = sumAz / samples;
    float ax = sumAx / samples;

    float initRoll = atan2(ay, az) * RAD_TO_DEG;
    float initPitch = atan2(-ax, sqrt(ay*ay + az*az)) * RAD_TO_DEG;
    physical_skew_angle = initRoll;

    ekf.setInitialAttitude(initRoll, initPitch, 0);
    Serial.printf("Calibrated — Roll: %.1f  Pitch: %.1f\n", initRoll, initPitch);
}

void resetController() {
    rollIntegral = 0;
    lastServoOffset = 0;
    lowGStartTime = 0;
    ekf.reset();
    calibrateSensors();
}

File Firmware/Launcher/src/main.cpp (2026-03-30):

/*
 * LAUNCHER ESP32 CODE (WiFi AP + Comm Relay + Fusion + GPS + Barometer)
 * V4 - Fully Non-Blocking & GPS Status Tracking
 */

#include <Arduino.h>
#include <SPI.h> 
#include <Wire.h>
#include <WiFi.h>
#include <WiFiUdp.h>
#include <ESP32Servo.h>
#include <QMC5883LCompass.h>
#include <TinyGPS++.h>
#include <Adafruit_BMP085.h>

const char* ssid = "ROCKET_LAUNCHER";
const char* password = "launch_secure"; 
const int udpPort = 4444;
WiFiUDP udp;
IPAddress dashboardIP;
bool dashboardConnected = false;

const int RX2_PIN = 16;
const int TX2_PIN = 17;
const int SWITCH_PIN = 5;         
const int BUTTON_PIN = 18;        
const int LED_PIN = 23;           
const int BUZZER_PIN = 2;         
const int LAUNCHER_SERVO_PIN = 19; 
const int I2C_SDA = 21;
const int I2C_SCL = 22;
const int GPS_RX_PIN = 4; // Using D4 for GPS RX

const int SERVO_ON = 170;
const int SERVO_OFF = 55;

enum SystemState { SAFE, ARMING, READY, IGNITING };
SystemState currentState = SAFE;

Servo launcherServo;
QMC5883LCompass compass;
TinyGPSPlus gps;
HardwareSerial SerialGPS(1); // Use Hardware Serial 1 for GPS
Adafruit_BMP085 bmp;

// Environment Filter Variables
float filteredAlt = 0.0;
const float ALT_ALPHA = 0.15; // Filter strength for Altitude (0.0 to 1.0)

unsigned long lastHeartbeatTime = 0;
const unsigned long HEARTBEAT_TIMEOUT = 2000; 

float mpu_ax = 0.0, mpu_ay = 0.0, mpu_az = 0.0;
float cal_ay = 0.0, cal_az = 1.0; 

const float MAG_OFFSET_X = -211.00;
const float MAG_OFFSET_Y = 897.00;
const float MAG_OFFSET_Z = -514.50;
const float MAG_SCALE_X = 0.988;
const float MAG_SCALE_Y = 0.971;
const float MAG_SCALE_Z = 1.044;

bool udpLaunchTriggered = false;
bool rocketReady = false; 
bool rocketIgnited = false; 

void buzzerOn() { digitalWrite(BUZZER_PIN, LOW); }
void buzzerOff() { digitalWrite(BUZZER_PIN, HIGH); }

void beep(int ms) { buzzerOn(); delay(ms); buzzerOff(); }
void successTone() { beep(150); delay(150); beep(150); }
void errorTone() { for(int i=0; i<5; i++) { beep(100); delay(100); } }

bool isSwitchArmed() { return digitalRead(SWITCH_PIN) == LOW; }
bool isButtonPressed() { return digitalRead(BUTTON_PIN) == LOW; }

void abortSequence(String reason);
void waitForSwitchReset();
void updateAndPrintFusion();
void processGPS();

void setup() {
    Serial.begin(115200); 
    
    // Configure hardware serial buffer to prevent data overflow at 115200 baud
    Serial2.setRxBufferSize(2048); 
    Serial2.begin(115200, SERIAL_8N1, RX2_PIN, TX2_PIN);
    Serial2.setTimeout(20); 

    // Setup GPS Serial on the RX pin (ignoring TX by passing -1)
    SerialGPS.begin(9600, SERIAL_8N1, GPS_RX_PIN, -1);

    Serial.println("Starting WiFi Access Point...");
    WiFi.softAP(ssid, password);
    IPAddress IP = WiFi.softAPIP();
    Serial.print("AP IP address: ");
    Serial.println(IP);
    udp.begin(udpPort);

    Wire.begin(I2C_SDA, I2C_SCL);
    compass.init();
    compass.setSmoothing(10, true);
    Wire.setClock(400000); 

    pinMode(SWITCH_PIN, INPUT_PULLUP);
    pinMode(BUTTON_PIN, INPUT_PULLUP);
    pinMode(LED_PIN, OUTPUT);
    pinMode(BUZZER_PIN, OUTPUT);
    buzzerOff();
    digitalWrite(LED_PIN, LOW);
    
    launcherServo.setPeriodHertz(50); 
    launcherServo.attach(LAUNCHER_SERVO_PIN);
    launcherServo.write(SERVO_OFF); 

    if (bmp.begin()) {
        filteredAlt = bmp.readAltitude(); // Seed the filter
        Serial.println("BMP180 initialized.");
    } else {
        Serial.println("Warning: BMP180 not found.");
    }

    // --- GPS STARTUP CHECK ---
    Serial.println("Checking GPS NMEA Data...");
    unsigned long gpsStart = millis();
    bool gpsWorks = false;
    
    while (millis() - gpsStart < 5000) {
        while (SerialGPS.available() > 0) {
            char c = SerialGPS.read();
            if (c == '$') { // Standard start of an NMEA sentence
                gpsWorks = true;
            }
            gps.encode(c);
        }
        if (gpsWorks) break;
        delay(10);
    }

    if (!gpsWorks) {
        Serial.println("CRITICAL: NO GPS DATA! ABORTING LAUNCHER STARTUP.");
        while (true) { // Halt and play error loop
            digitalWrite(LED_PIN, HIGH);
            errorTone();
            digitalWrite(LED_PIN, LOW);
            delay(1000);
        }
    }
    
    Serial.println("GPS Test Passed.");
    delay(500); 
    successTone();
}

void sendToDashboard(String msg) {
    if (dashboardConnected) {
        udp.beginPacket(dashboardIP, udpPort);
        udp.println(msg);
        udp.endPacket();
    }
}

void processGPS() {
    while (SerialGPS.available() > 0) {
        gps.encode(SerialGPS.read());
    }
}

void processSerial2() {
    while (Serial2.available()) {
        String msg = Serial2.readStringUntil('\n');
        msg.trim();

        if (msg.indexOf("READY") != -1) {
            rocketReady = true; 
        }
        else if (msg.indexOf("IGNITED") != -1) {
            rocketIgnited = true;
        }
        else if (msg.startsWith("DATA,") || msg.startsWith("ALIVE")) {
            lastHeartbeatTime = millis();
            
            if (msg.startsWith("DATA,")) {
                int c[12];
                int nCommas = 0;
                c[0] = msg.indexOf(',');
                for (int i = 1; i < 12 && c[i-1] > 0; i++) {
                    c[i] = msg.indexOf(',', c[i-1] + 1);
                    nCommas = i;
                }

                if (nCommas >= 9) {
                    mpu_ax = msg.substring(c[0]+1, c[1]).toFloat();
                    mpu_ay = msg.substring(c[1]+1, c[2]).toFloat();
                    mpu_az = msg.substring(c[2]+1, c[3]).toFloat();

                    String roll = msg.substring(c[3]+1, c[4]);
                    String rate = msg.substring(c[4]+1, c[5]);
                    String out = msg.substring(c[5]+1, c[6]);
                    String state = msg.substring(c[6]+1, c[7]);
                    String kp = msg.substring(c[7]+1, c[8]);
                    String kd, extra;
                    if (nCommas >= 10 && c[10] > 0) {
                        // V5: ...,Kp,Ki,Kd,biasX,Vbatt
                        kd = msg.substring(c[9]+1, c[10]);
                        extra = msg.substring(c[10]+1);
                    } else {
                        // V4: ...,Kp,Kd,skew
                        kd = msg.substring(c[8]+1, c[9]);
                        extra = msg.substring(c[9]+1);
                    }

                    sendToDashboard("T," + String(millis()) + "," + roll + "," + rate + "," + out);
                    sendToDashboard("STATUS:" + state + "," + kp + "," + kd + "," + extra);
                }
            }
        }
    }
}
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

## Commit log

2026-03-29 feat: Add comprehensive simulation framework and improved firmware
    Major additions:
    - 6-DOF flight dynamics simulator with GPU acceleration support
    - Extended Kalman Filter for drift-free attitude estimation (6x improvement)
    - GPU-accelerated PID gain optimizer using differential evolution
    - Monte Carlo trajectory analysis for reliability testing
    - Reinforcement learning controller using PPO algorithm
    - Improved 3-axis stabilization firmware with anti-windup PID
    SLURM job scripts for HPC cluster execution:
    - run_pid_optimizer.sh: Optimize control gains
    - run_monte_carlo.sh: Statistical trajectory analysis
    - run_rl_training.sh: Train neural network controller
    - run_full_analysis.sh: Complete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
    [attitude_ekf.h, main_improved.cpp]
2026-03-29 fix: Parallelize PID optimizer and improve simulation stability
    Changes:
    - Fixed ProcessPoolExecutor pickling issue with module-level worker function
    - Added PYTHONUNBUFFERED for real-time job output
    - Parallelized Differential Evolution initial population and trial evaluation
    - Adjusted canard aerodynamic model for simplified roll control
    - Increased canard effectiveness (area: 0.001m², lift_coef: 0.3)
    - Reduced Monte Carlo uncertainty parameters for realistic testing
    - Relaxed success criteria to roll_rms < 30°
    Results from cluster runs:
    - PID optimization completed in 165s with 16 workers
    - Optimized gains: Kp=1.47, Kd=0.31
    - Monte Carlo shows ~1% success rate (wind sensitivity issue)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
2026-03-29 Overhaul simulation physics, optimize gains, and add documentation
    - Rewrite 6-DOF aerodynamic model with correct canard moments,
    Dryden wind turbulence, CNa-based restoring forces, and
    non-dimensional rate damping
    - Simplify controller to roll-only PD(I) matching real firmware
    (D-term from gyro rate, all 4 canards deflect identically)
    - Fix PID optimizer objective to minimize burn-phase roll RMS
    - Fix Monte Carlo with per-run seeded wind, burn-phase metrics,
    elapsed time reporting, and parallel pickling
    - Add automatic apogee detection to V5 firmware with
    backward-compatible V4 telemetry format
    - Fix WIRING.md pin assignments to match actual firmware source
    - Add SIMULATION.md, FI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
    [main_improved.cpp]
2026-03-29 Simulation: six-axis canard control, motor impulse scaling, CFD serial mesh
    - rocket_dynamics: MotorProfile scales thrust to 10 N·s; mix_canards + 3-axis PID;
    differential canard moments; pitch_rms_burn; canard area 9 cm²
    - pid_optimizer: --six-axis DE; expanded Kp/Kd bounds; unified worker
    - monte_carlo: full gains dict, elapsed_seconds fix, pitch success when pitch active
    - design_sweep: --from-json fast STL export; fin/canard positions aligned with Barrowman
    - rocket_geometry: watertight nose base cap for CFD
    - cfd/run_case.py: --serial-mesh path; run_cfd.sh bash+Lmod+serial mesh+669mm length
    - jobs: run_pid_sixaxis.sh; cluster defaults remain roll-only DE in run_pid_optimizer
    - Firmw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
    [Folding Rocket.f3z, Launcher Platform.f3z, Rocket Nozzle.f3z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]
2026-03-29 Fix CFD job paths for SLURM; add STL preview renders and script
    - run_cfd.sh: resolve repo root from submit dir/STL path so cluster copies of the script still find cad/ and Simulation/.
    - Add Simulation/scripts/render_stl_previews.py (headless matplotlib) and docs/cad-previews/*.png for baseline CAD and top sweep candidates.
    Made-with: Cursor
2026-03-29 Nicer CAD previews: Lambert shading and improved-deployed preset
    - rocket_geometry.generate_rocket: optional return_parts for multi-color renders.
    - render_stl_previews: dark theme, directional light, triptych views; --preset improved-deployed shows full fin/canard span with distinct materials.
    - Refresh docs/cad-previews PNGs; add improved_rocket_deployed_shaded.png.
    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
2026-03-30 Full system overhaul: fix CFD pipeline, firmware bugs, launcher redesign
    CFD fixes:
    - Change hardcoded 'rocket' patch to regex "rocket.*" in all BC templates,
    controlDict forceCoeffs, and snappyHexMeshDict layer controls
    - Reduce background mesh from d/4 to d*2 cell size (was 13.5M cells → OOM)
    - Increase maxGlobalCells from 4M to 8M
    - Use limited corrected 0.33 for laplacian/snGrad schemes
    - cellLimited Gauss linear 1 for all gradSchemes
    - Remove SIMPLEC consistent, raise p relaxation to 0.5
    - Increase nNonOrthogonalCorrectors from 1 to 2
    Firmware fixes:
    - Fix EKF getGyroBiasX() unit mismatch: return rad/s (renamed getGyroBiasXRaw)
    so D-term subtraction in main_improved.cpp uses cons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
    [rail_launcher.stl, rocket_assembly_rail.stl]
2026-03-30 Fix run_cfd.sh: convert STL path to absolute before cd
    The relative STL path broke after cd to Simulation/ because it was
    resolved from the jobs/ directory. Now uses realpath-equivalent to
    make the path absolute immediately after resolution.
    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
2026-03-30 Fix CFD solver startup and MPI CUDA crash
    - Add pRefCell/pRefValue to fvSolution (simpleFoam requires explicit
    pressure reference when not using SIMPLEC consistent mode)
    - Set OMPI_MCA_mpi_cuda_support=0 in run_cfd.sh to prevent OpenMPI
    CUDA-aware transport segfault on non-GPU nodes
    - Move locationInMesh from 90% to 50% of domain half-width (was falling
    outside mesh after snappyHexMesh refinement)
    - Update monte_carlo_results.json from successful job 2049 (14.7%, 2000 runs)
    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
2026-03-30 Fix CFD STL orientation and bump cluster resources to 32 cores
    - Rotate STL from +Z-up to +X-forward before CFD (rocket_geometry
    generates along +Z but simpleFoam flow is along +X)
    - Add pRefCell/pRefValue and magUInf to OpenFOAM templates
    - Disable CUDA-aware MPI for non-GPU nodes
    - Generate clean watertight baseline STL for CFD
    - Bump job scripts to 32 cores / 96 GB per node
    - Increase RL training to 2M timesteps on CPU
    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
    [rocket_baseline_clean.stl]
2026-03-30 Add CFD sweep results (5 designs) and updated RL policy (2M steps)
    CFD results (all with corrected STL rotation):
    - Baseline: Cd=0.40 @ v40_a0
    - Candidate #1 (VK): Cd=0.36 (-10%)
    - Candidate #2 (conical): Cd=0.41
    - Candidate #5 (ogive): Cd=0.35
    - Rail rocket w/ buttons: Cd=0.36
    RL PPO trained 2M steps on CPU: mean reward -63.8, roll RMS
    19.7°, altitude 12.7m. Policy needs reward shaping refinement.
    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
2026-03-30 Full simulation improvement: CFD fix, RL overhaul, firmware RL integration
    CFD pipeline:
    - Fix critical coeff extraction bug (was reading Cd(f)/Cd(r) as Cl/Cm)
    - Parse all 13 OpenFOAM forceCoeffs columns correctly
    - Make dragDir/liftDir AoA-aware (rotate with freestream)
    - Add --refinement-level (1/2/3) for mesh independence studies
    - Parametric maxGlobalCells via snappyHexMeshDict template
    - Add canard deflection to rocket_geometry.py for control sweeps
    Aero table bridge:
    - New cfd_aero_table.py with RegularGridInterpolator for Cd(V,AoA)
    - rocket_dynamics.py uses CFD tables when available, falls back to Barrowman
    - monte_carlo.py accepts --aero-table for CFD-driven MC analysis
    RL controll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
    [main_improved.cpp]
